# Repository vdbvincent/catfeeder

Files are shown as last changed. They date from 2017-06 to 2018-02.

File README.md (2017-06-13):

# Catfeeder

Example for building your own automatic catfeeder built with Arduino uno

## About

This is an example, with software provided, to automate the feeding of your pets.

This repo contains schemas and source code.

## How does it work ?

The feeder dispenser is very simple.
It consists of a self-made wood frame and an archimedes screw controled by an Arduino Uno.
The arduino drives the motor which himself rotates the screw. The food is then pushed into a spilway.

It offers a menu, through a LCD screen, in which you can find :
- Time setting : you need to set the time at on power-up.
- Alarms programming : up to 5 alarms can be set in a day to program a food distribution.
- Food distribution : you can choose the amount of food to be dispensed and then operate the engine.

A sleep mode is used to turn off the LCD screen to prevent overconsumption. It appears after 30 secondes of inactivity.
In this mode, the 'OK' button switches the display back on. The others help to distribute food quickly (Quickfeed shorcut).

<p align="center">
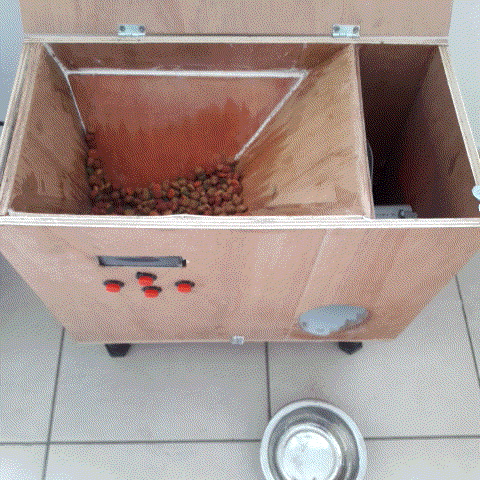
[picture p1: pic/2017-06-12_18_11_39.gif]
  
</p>

## Menu screen

<p align="center">
  main screen  <br />
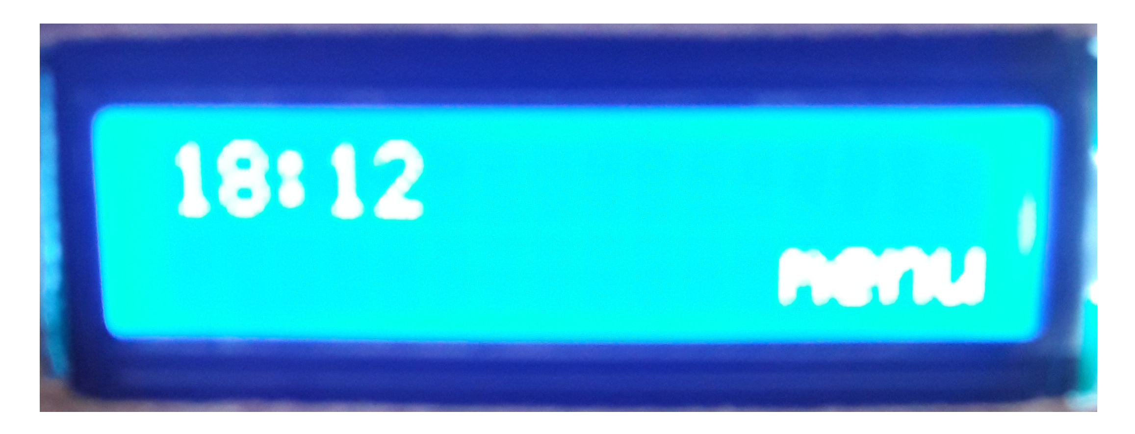
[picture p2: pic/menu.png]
  
</p>

<p align="center">
  main menu  <br />
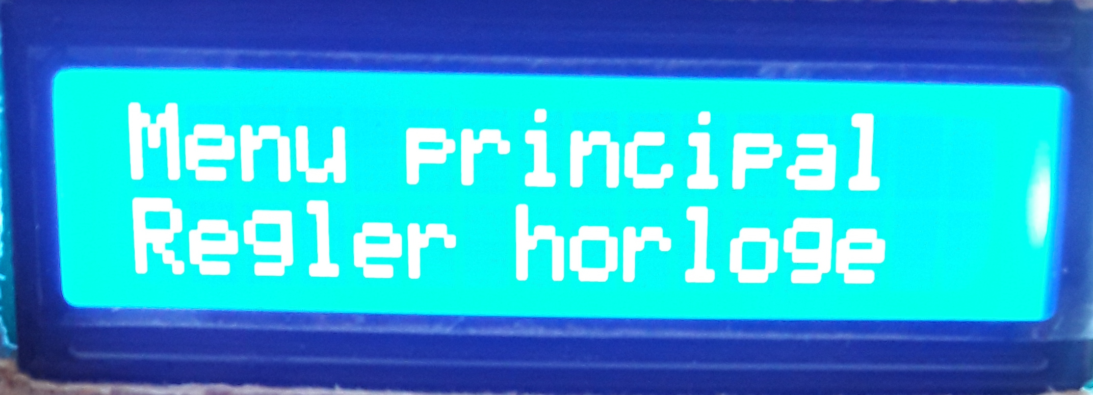
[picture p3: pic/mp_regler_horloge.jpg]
  
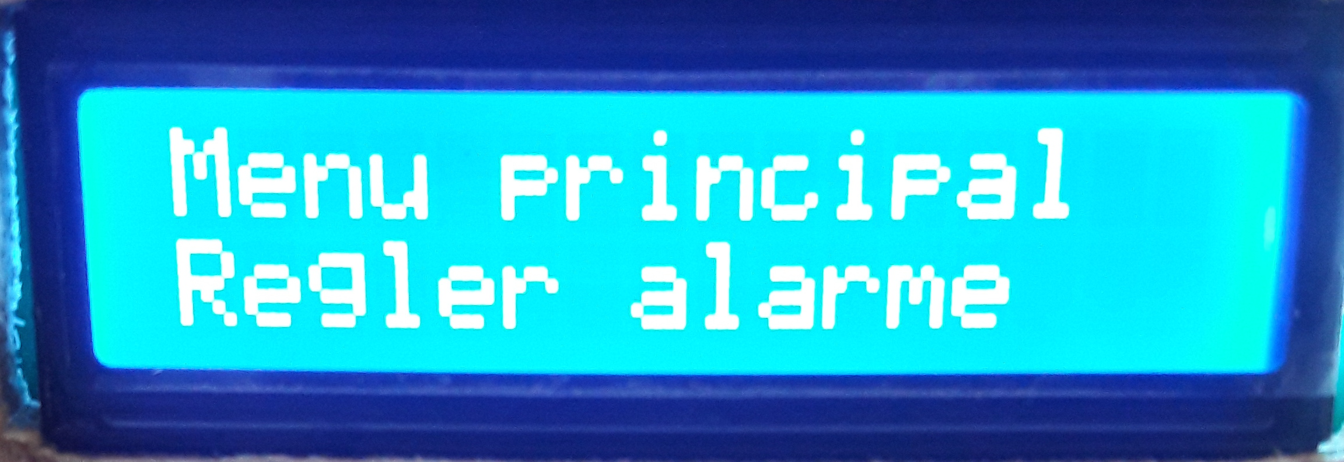
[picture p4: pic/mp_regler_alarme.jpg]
  
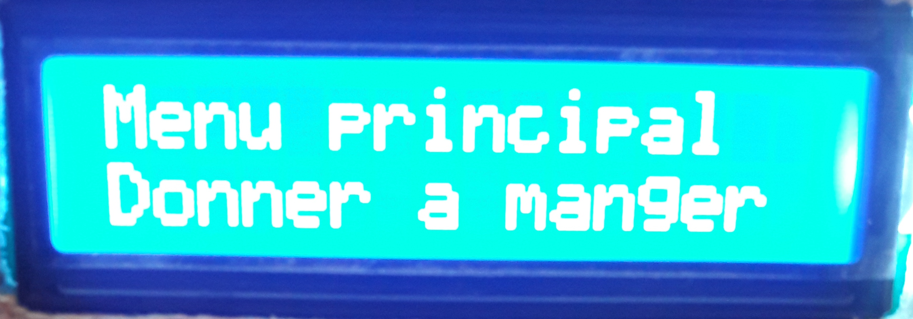
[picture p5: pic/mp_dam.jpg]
  
</p>

<p align="center">
  Feed the cat  <br />
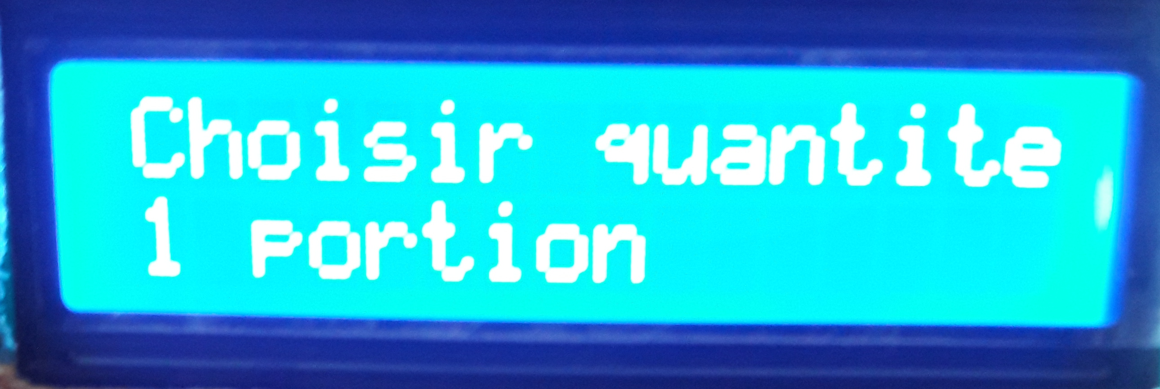
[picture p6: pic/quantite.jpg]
  
</p>

<p align="center">
  Set an alarm  <br />
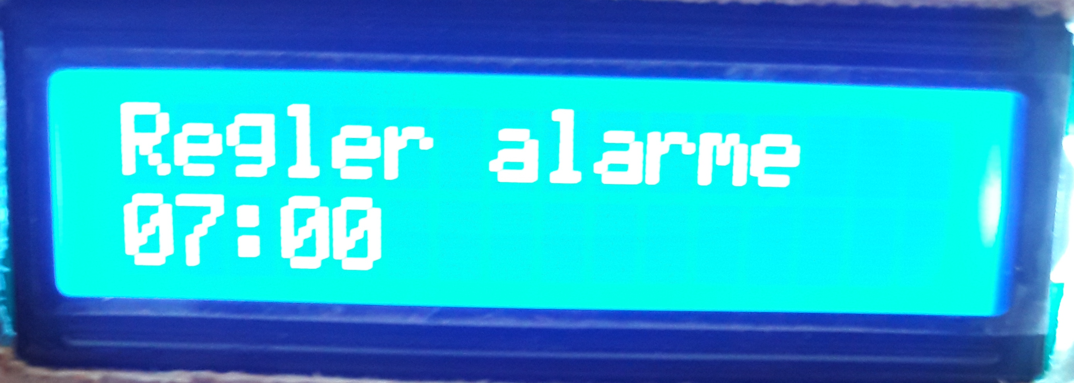
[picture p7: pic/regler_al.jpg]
  
</p>

## Electronics
#### Components list
- Arduino Uno
https://www.amazon.com/Arduino-Uno-R3-Microcontroller-A000066/dp/B008GRTSV6/
- 9v DC/DC
https://www.amazon.com/MT3608-DC-DC-Power-Module-Booster/dp/B01N41MM10
- Relay
https://www.amazon.com/Tolako-Arduino-Indicator-Channel-Official/dp/B00VRUAHLE/
- LCD screen with I2C interface
https://www.amazon.com/Frentaly-Backlight-Arduino-MEGA2560-letters/dp/B0182N00LU/
- Switchs push button
https://www.amazon.com/Mini-Momentary-Button-Switch-Terminal/dp/B013JTIKBY/
- Power supply
https://www.amazon.fr/Aukru-Universel-Alimentation-adaptateur-chargeur/dp/B00MVLJ6NI/

#### Diagram
<p align="center">
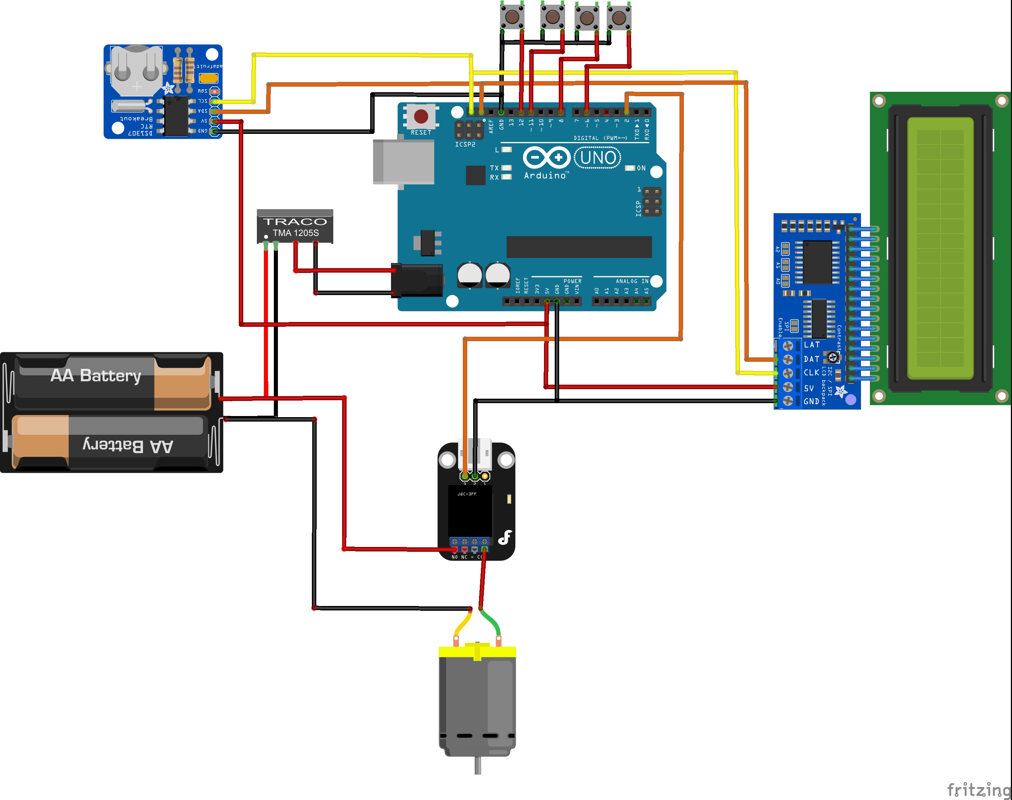
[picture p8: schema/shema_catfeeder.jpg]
  
</p>

## Frame

<p align="center">
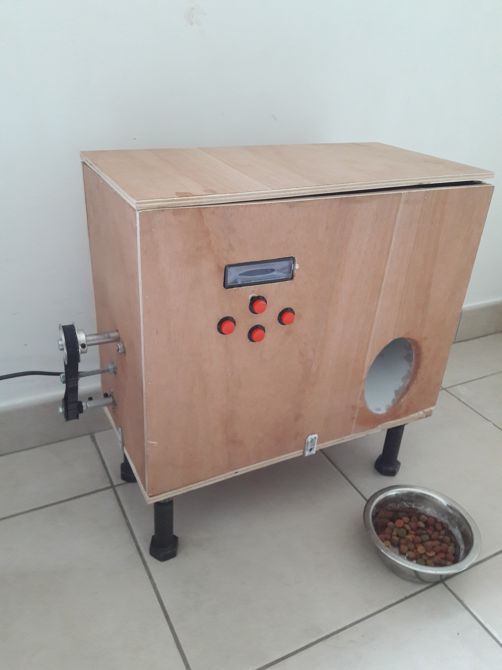
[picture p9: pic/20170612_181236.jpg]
  
</p>

<p align="center">
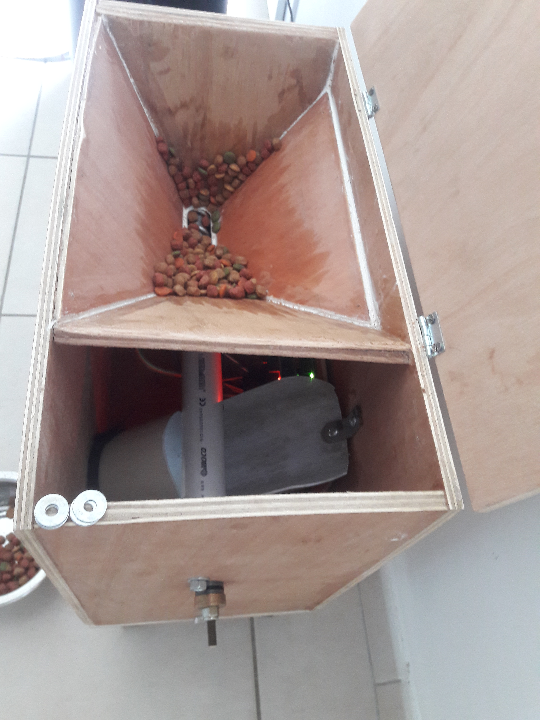
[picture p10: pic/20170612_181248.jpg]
  
</p>

## Install software
1/ Install Arduino environnement : https://www.arduino.cc/en/Main/Software

2/ Download the source code or clone it : "git clone https://github.com/vdbvincent/catfeeder.git"

3/ Put all the *.h and *.ino files into a named "catfeeder" folder

4/ Upload the soft into your Arduino board

## Contribute
Please, feel free to send me a pull request !

## Next to do
* RF communication
* Android interface for settings
* Feelling sensor

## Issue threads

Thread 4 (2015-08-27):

Upgrade v1.1

vdbvincent, 2015-08-27:
Fonctionnalités et améliorations attendues pour la v1.1

1/ Creer des modes de fonctionnement.
- Mode démarrage : Tant que l'heure n'est pas configuré, faire clignoter l'écran d'acceuil pour attirer l'attention de l'utilisateur. Autoriser la distribution toutes les 8 heures. Le menu doit bloquer le réglage de l'alarme.
- Mode nominal : Si l'heure est configurée, l'écran d'acceuil doit être fixe et afficher le temps restant avant la prochaine distribution avec un symbole 'reveil'. Si aucune alarme, laisser vide. Le menu ne doit plus bloquer le réglage de l'alarme.
- Mode distribution : Afficher le texte "please wait ..." prioritaire sur l'affichage du menu en tout moment.

2/ Gestion de logs plus fine.

Permettre d'activer le retour de logs via la liaison série pour chaque tâche via une macro.
Permettre d'activer ou d'inhiber le retour de logs pour le logiciel complet.
Ajouter des niveaux de criticité à prendre en compte pour la génération du log
-> Centraliser la gestion des logs dans log.c et proposer une fonction printf() à l'ensemble du logiciel avec ajout d'arguements infinis.
[ ] A tester
[ ]  A reporter dans toutes les taches

3/ Paramétrer le temps d'affichage de l'écran de démarrage.
Source menu.ino actuellement en macro doit être passé en argument de la fonction setup().
[x] Done.

4/ Sauvegarder en EEPROM la configuration de toutes les alarmes configurées.

5/ Gestion dynamique du rétro-éclairage du LCD
Modifier la conception hardware afin de permettre un pilotage du rétro-éclairage par le micro µ. (trouver une sortie logique)
L'écran LCD doit être allumé au max 1 minute depuis la dernière action utilisateur.
Si le menu n'est pas sur l'écran d'acceuil, les configurations en cours doivent être annulées.
Au réveil de l'écran, le menu d'acceuil doit être affiché.

6/ Gestion des boutons via un pont diviseur de tension
Brancher les boutons sur une seule entrée analogique via un montage pont diviseur.
Permettra de libérer 3 pins analogiques.

Closed 2017-06-09.

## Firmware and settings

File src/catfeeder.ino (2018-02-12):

/*
 * catfeeder.ino
 *
 *  Created on: 31 juil. 2015
 *      Author: vincent
 */

#include "catfeeder.h"
#include "mcubind.h"
#include "boutons.h"
#include "logs.h"
#include "clock.h"
#include "alarme.h"
#include "moteur.h"
#include "menu.h"
#include "manager.h"

// Variables globales
static int c10 = 0;
static int tmp = 0;

/*
	TODO :
		- Ajouter un capteur de courant pour controler l'intensité du moteur
		- Ajouter un pont en H a base de relais pour faire tourner le moteur dans les 2 sens
		- Ajouter un module de communication RF
		- Ajouter un système de sauvegarde de codes defauts en eeprom
		- Ajouter un fusible en entrée de l'alimentation
*/

void setup()
{
	// OS
	init_mcubind();
	//print_log(INFO, "Initialisation\n");
	clock_setup();
	boutons_setup(100);  // init du process bouton avec un delai de filtrage de 10ms
	moteur_setup();
	manager_setup();
	menu_setup(2); // temps du welcom screen de 2s

	//-------------------
	// A faire seulement une fois au premier demarrage
	//-------------------
	/* clock tmp;
	 tmp.heures = 0;
	 tmp.minutes =  0;
	 eeprom_ecrire_alarme(tmp, EEPROM_AL1);
	 eeprom_ecrire_alarme(tmp, EEPROM_AL2);
	 eeprom_ecrire_alarme(tmp, EEPROM_AL3);
	 eeprom_ecrire_alarme(tmp, EEPROM_AL4);
	 eeprom_ecrire_alarme(tmp, EEPROM_AL5);
	 */
	
	alarme_setup();
}

void loop()
{
	logs_idle();
	menu_idle();
	logs_idle();
	clock_idle();
	delay(5);
}


void every10ms(void)
{
	// TOUTES LES 10 MILLISECONDES
	switch (c10) 
	{
		case 0:
			clock_every100ms();
		break;
		case 1:
			boutons_every100ms();
		break;
		case 2:
			alarme_every100ms();
		break;
		case 3:
			moteur_every100ms();
		break;
		case 4:
			manager_every100ms();
		break;
	}
	if (c10 >= 10)
		c10 = 0;
	else
		c10 ++;
}

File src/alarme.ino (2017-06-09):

/*
 * alarme.c
 *
 *  Created on: 31 juil. 2015
 *      Author: vincent
 *
 */
#include "alarme.h"

#define delais_sec 5
#define delais (10*delais_sec)

// Variables globales
static Alarme_t al_pool[MAX_COUNT_ALARM];
//static Minuteur_t * mi_pool[MAX_COUNT_MINUT];
static Minuteur_t mi_pool[MAX_COUNT_MINUT];
static uint8_t m_nbMin = 0;

void alarme_setup(void)
{
	int i;
	clock ctmp;
	uint8_t indice = 0;
	
	// Init de la banque de minuteries à NULL
	for (i = 0; i < MAX_COUNT_MINUT; i++)
	{
		mi_pool[i].delai = 0;
	}

	for (i = 0; i < MAX_COUNT_ALARM; i++)
	{
		al_pool[i].horaire.heures = 0;
		al_pool[i].horaire.secondes = 0;
		al_pool[i].horaire.minutes = 0;
	}

	// Charger les alarmes stockées en eeprom
	indice = 0;
	ctmp = eeprom_lire_alarme(indice);
	indice ++;
	while(indice <= 5)
	{
		#ifdef ADEBUG
			char tabtmp2[32];
			sprintf(tabtmp2, "al : init %d:%d\n", ctmp.heures, ctmp.minutes);
			//print_log(DEBUG, tabtmp2);
			printstr(tabtmp2);
			#endif

		if (ctmp.heures != 0 || ctmp.minutes != 0)
		{
			

			alarme_setAlarme(ctmp, &manager_procAlarme, 0);  // Toujours appeler la methode du manager
		}
		ctmp = eeprom_lire_alarme(indice);
		indice ++;
	}
}

void alarme_every100ms(void)
{
	static uint8_t cmp_100ms = 0;
	uint8_t i = 0;
	
	// Gestion de l'alarme
	// 1minute = 60 secondes = 60000ms = 600.100ms
	// 5secondes = 5000ms = 50 * 100ms
	
	if (cmp_100ms == 0)
	{
		alarme_every1mn();
	}
	cmp_100ms ++;  // incrementer le compteur
	if (cmp_100ms >= delais)
	{
		cmp_100ms = 0;
	}
	
	// Gestion de la minuterie
	if (m_nbMin > 0)  // m_nbMin représente le nb de minuteurs
	{
		for (i = 0; i < MAX_COUNT_MINUT; i++)
		{
			// Tester le pointeur
			//if (mi_pool[i] != NULL)
			if (mi_pool[i].delai > 0)
			{
				// Tester le temps restant
				if (mi_pool[i].delai > 1)
				{
					// Décrementer le délai
					mi_pool[i].delai --;
				}
				else
				{
					#ifdef ADEBUG
					print_log(DEBUG, "al : set timer\n");
					#endif
					// La minuterie est arrivée à expiration, déclencher le callback
					(*mi_pool[i].foncteur)();
					//delete mi_pool[i];
					//mi_pool[i] = NULL;
					mi_pool[i].delai = 0;
					mi_pool[i].foncteur = NULL;

					if (m_nbMin > 0)
						m_nbMin --;
				}
			}
		}
	}
}

void alarme_every1mn(void)
{
	// vérifier toutes les minutes si une alarme déclenche
	uint8_t i = 0;
	uint8_t tmp = 0;
	clock heure_courante;

	heure_courante = clock_getClock();

	while (i < MAX_COUNT_ALARM)
	{
		if (al_pool[i].horaire.heures != 0 || al_pool[i].horaire.minutes != 0)
		{
			if (al_pool[i].horaire.heures == heure_courante.heures
			 && al_pool[i].horaire.minutes == heure_courante.minutes)
			{
				if (heure_courante.secondes > (al_pool[i].horaire.secondes - 5)
				 && heure_courante.secondes < (al_pool[i].horaire.secondes + 5))
				{
					#ifdef ADEBUG
					print_log(DEBUG, "al : declenchement alarme\n");
					#endif
					(*al_pool[i].foncteur)();
					tmp ++;
					al_pool[i].foncteur = NULL;
				}
			}
		}
		i ++;
	}
	#ifdef ADEBUG
	if (tmp != 0)
	{
		print_log(DEBUG, "al : + alarmes\n");
	}
		
	#endif
}

// Méthode permettant de regler une alarme. Retourne 0 en cas d'echec
char alarme_setAlarme(clock p_al, void (*callback)(void), uint8_t p_toMemory)
{
	char ret = 0;
	uint8_t indice = 0;

	// Recherche de la premiere position vide
	while ((al_pool[indice].horaire.heures != 0 || al_pool[indice].horaire.minutes != 0) && indice < MAX_COUNT_ALARM)
	{
		indice ++;
	}

	if (indice < MAX_COUNT_ALARM)
	{
		// ici indice pointe sur le premier element vide du tableau al_pool
		// Ajout de l'alarme
		//al_pool[indice].horaire = p_al;
		al_pool[indice].horaire.secondes = p_al.secondes;
		al_pool[indice].horaire.minutes = p_al.minutes;
		al_pool[indice].horaire.heures = p_al.heures;
		al_pool[indice].foncteur = callback;
		
		if (p_toMemory > 0)
		{
			// Enregistrement en eeprom
			eeprom_ecrire_alarme(al_pool[indice].horaire, indice);
		}

		#ifdef ADEBUG
		char tabtmp[32];
		sprintf(tabtmp, "al : set %d:%d\n", al_pool[indice].horaire.heures, al_pool[indice].horaire.minutes);
		print_log(DEBUG, tabtmp);
		#endif

		ret = 1;
	}

	return ret;
}

// Méthode permettant de régler une minuterie. Retourne 0 en cas d'échec
char alarme_setMinuteur(uint16_t p_delai, void (*callback)(void))
{
	char ret = 0;
	int i = 0;
	Bool b_exit = False;
	// Recherche du premier emplacement libre
	while ((i < MAX_COUNT_MINUT) && (b_exit == False))
	{
		//if (mi_pool[i] == NULL)
		if (mi_pool[i].delai == 0)
		{
			b_exit = True;
		}
		else
		{
			i ++;
		}
	}
	if (b_exit == True)
	{
		// Un emplacement vide a été trouvé à i
		mi_pool[i].delai = p_delai * 10;  // Délais en sec x 10 car ps de 100ms
		mi_pool[i].foncteur = callback;
		m_nbMin ++;
		ret = 1;
		#ifdef ADEBUG
		print_log(DEBUG, "al : minuteur set\n");
		#endif
	}
	return ret;
}

//Alarme_t * alarme_getAlarme(void)
clock alarme_getAlarme(uint8_t indice)
{
	if (indice < 0 || indice >= MAX_COUNT_ALARM)
	{
		clock tmp;
		tmp.heures = 0;
		tmp.minutes = 0;
		tmp.secondes = 0;
	}
	else
	{
		#ifdef ADEBUG
		char tabtmp2[32];
		sprintf(tabtmp2, "al : get %d:%d\n", al_pool[indice].horaire.heures, al_pool[indice].horaire.minutes);
		print_log(DEBUG, tabtmp2);
		#endif
		return al_pool[indice].horaire;
	}
}


// Fonction permettant de supprimer une alarme en fonction
// de sa position dans la liste chainée
Bool alarme_delAlarme(uint8_t p_selection)
{
	Bool b_return = True;

	if (p_selection < MAX_COUNT_ALARM)
	{
		if (al_pool[p_selection].horaire.heures != 0 || al_pool[p_selection].horaire.minutes != 0)
		{
			// Suppression de l'alarme
			al_pool[p_selection].horaire.heures = 0;
			al_pool[p_selection].horaire.minutes = 0;
			al_pool[p_selection].horaire.secondes = 0;
			// Propager la suppression dans l'eeprom
			eeprom_ecrire_alarme(al_pool[p_selection].horaire, p_selection);

			#ifdef ADEBUG
			char tabtmp[32];
			sprintf(tabtmp, "al : mod %d:%d\n", al_pool[p_selection].horaire.heures, al_pool[p_selection].horaire.minutes);
			print_log(DEBUG, tabtmp);
			#endif
		}
		else
		{
			b_return = False;
		}
	}
	else
	{
		b_return = False;
	}

	return b_return;
}

void alarme_modify(clock p_clock, uint8_t p_indice)
{
	uint8_t i = 0;

	if (p_indice < MAX_COUNT_ALARM)
	{
		if (p_clock.heures != 0 || p_clock.minutes != 0)
		{
		    al_pool[p_indice].horaire.heures = p_clock.heures;
			al_pool[p_indice].horaire.minutes = p_clock.minutes;
			al_pool[p_indice].horaire.secondes = p_clock.secondes;
			// Propager la modification dans l'eeprom
			eeprom_ecrire_alarme(al_pool[p_indice].horaire, p_indice);
		}
	}
}

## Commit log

2015-08-26 catFeeder v1.0
    [shema.fzz]
2015-08-27 Correction schema elec
    [shema.fzz]
2015-08-27 Reset heure au demarrage
    [alarme.ino, catfeeder.ino, clock.ino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]
2015-08-28 Correction période timer2 à 10ms
    [catfeeder.ino]
2015-08-28 Paramétrage tempo démarrage
    Ajout paramètre du temps d'affichage de l'écran de démarrage
2015-08-28 Ajout gestionnaire de logs
2015-12-08 Lecture ADC ok + archi sequenceur mode arduino
2016-01-23 Ajout des menus (en cours)
2016-01-23 Methode pour supprimer une alarme Ajout des sources du manager
2016-01-25 Suppression de commentaires Ajout de pointeur en paramètres de fonction clock Ajout de la macro DEBUG Mise en route du managr
2016-01-29 Suppression du delete de la stucture horloge
2016-02-17 changement des menus en cours
2016-02-22 changement définition de la liste chainée
2016-02-22 changement d'allocation des item du menu setanalarme
2016-02-22 bug affichage si 5 alarmes et al1 declenchee puis menu alarme
    [alarme.ino, common.h, lcd.ino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]
2016-02-24 correction gestion memoire reste bug sur changement alarme
    [alarme.ino, clock.ino, common.h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]
2016-02-24 bug pointeur dans menu resolu menu ok bug dans seq alarme 1mn
    [alarme.ino, common.h, manager.ino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]
2016-02-25 Ajout de la macro F()
2016-02-25 Suppression de commentaires
2016-02-25 Correction bug sur calcul de 1minute
    [alarme.ino]
2016-02-26 Correction du bug de declenchement alarme Correction bug menu modification alarme Suppression des macro F() sauf pour lcd.print car mal utilisée Manager passé en compil cond
    [alarme.ino, catfeeder.ino, lcd.ino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]
2016-03-01 menu alarme bug affichage
    [alarme.ino, lcd.ino, menu.ino]
2016-03-03 allocation dynamique du tab item menu alarme en global dans lcd -> bug resolu
    [lcd.ino, menu.ino]
2016-03-10 mise en place de l'eeprom alarmes sauvegardées en eeprom
2016-04-05 tentative de mise en place eeprom echouee
2016-04-05 changement du comportement des alarmes retour a une banque d'alarmes statiques
2016-04-06 correction bug increment de boucle
    [menu.ino]
2016-04-06 Alarme ok Eeprom ok menu ok nettoyage des commentaires dans le code
2016-05-18 creation du prototype de shield
    [shema.fzz, shield.fzz]
2017-05-15 correction cast
    [shema.fzz, shield.fzz]
2017-05-15 corrections cast 2
    [shema.fzz, shield.fzz]
2017-06-09 Tag Version 1.0
    [schema.fzz, shield.fzz]
2017-06-12 Ajout des images
2017-06-12 reorientation de l'image
2017-06-13 Mise a jour diagramme
    [schema.fzz]
2018-02-12 Activation des logs bouton
2018-02-13 Patch correctif fonctionnel menu
    [menu.ino]
